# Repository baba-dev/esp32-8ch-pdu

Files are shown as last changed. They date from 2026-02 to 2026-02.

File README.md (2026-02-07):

# esp32-8ch-pdu
DIY ESPHome powered 8 Channel Power Delivery Unit with code, 3d Case &amp; Instructions.

⚡ Ultimate DIY 8-Channel ESP32 PDU - Detailed at [BabaBuilds.com - DIY PDU Guide](https://bababuilds.com/blog/diy-8-channel-esp32-pdu/)




A professional-grade, 8-channel smart Power Distribution Unit (PDU) built on the ESP32 platform. This project replaces expensive commercial smart PDUs with a fully local, highly customizable solution featuring real-time RMS monitoring, OLED telemetry, and individual relay control.

## 🚀 Features

* **8x Independent Channels:** Control up to 8 AC sockets individually via Home Assistant.
* **True RMS Monitoring:** Measures Voltage (V), Current (A), Power (W), and Energy (kWh).
* **Web UI Calibration:** Calibrate voltage and current sensors directly from the browser—no code re-uploading required.
* **OLED Dashboard:** 1.3" display showing IP address, Real-time Voltage, and Total Load.
* **Reactive Status LEDs:** WS2812b strip provides visual feedback (Rainbow=Idle, Scan=Active, Strobe=Overload).
* **Safety First:** Uses "Normally Open" relay logic and thermal circuit protection.
* **Edge Automation:** Safety limits and LED effects run locally on the ESP32, independent of Wi-Fi.

## 🛠️ Hardware Bill of Materials

* **MCU:** ESP32 DevKit V1
* **Power:** Hi-Link HLK-PM01 (5V)
* **Relays:** 8-Channel 5V Relay Module (Low-Level Trigger)
* **Voltage Sensor:** ZMPT101B AC Voltage Sensor
* **Current Sensor:** WCS1700 Hall Effect Sensor (High Amp)
* **Display:** 1.3" I2C OLED (SH1106 or SSD1306 driver)
* **LEDs:** WS2812b Addressable RGB Strip
* **Protection:** 15A Thermal Circuit Breaker
* **Wiring:** 14 AWG (2.5mm²) for Mains, 22 AWG for Logic.

## 🔌 Pinout & Wiring

| Component | Pin Function | ESP32 GPIO | Notes |
| :--- | :--- | :--- | :--- |
| **Relays 1-8** | Control | 13, 14, 27, 26, 25, 33, 32, 4 | Active HIGH in Config |
| **I2C Display** | SDA | 21 | |
| **I2C Display** | SCL | 22 | |
| **WS2812b LEDs** | Data | 18 | |
| **ZMPT101B** | Analog Out | 34 | Calibrate via Pot first |
| **WCS1700** | Analog Out | 35 | **MUST** power with 5V (VIN) |

> **⚠️ WCS1700 Note:** You must power the WCS1700 sensor from the **VIN (5V)** pin. If powered via 3.3V, sensitivity is too low to detect small loads.

## 🎛️ How to Calibrate (The "Smart" Way)

This firmware allows dynamic calibration via the Web Server.

**1. Voltage Calibration:**
* Measure your actual wall voltage with a Multimeter (e.g., 236V).
* Open the Device Web Page (IP Address).
* Enter `236` in **"Calibrate: Real Voltage"**.
* Click **Action: Calibrate Voltage**.

**2. Current Calibration:**
* Plug in a known resistive load (e.g., a 1000W Heater).
* Ensure the "PDU Current" sensor shows *some* value (not 0.00).
* Enter `1000` in **"Calibrate: Known Load (Watts)"**.
* Click **Action: Calibrate Current**.

## ⚠️ Safety Warning

**DANGER: HIGH VOLTAGE**
This project involves 110V/220V Mains Electricity. Improper wiring can cause **fire, injury, or death**.

* Always unplug mains power before opening the case.
* Use wire ferrules on all screw terminals.
* Do not rely on the relays as a safety disconnect; use the physical switch/breaker.
* **Build at your own risk.** The authors accept no liability for damage or injury.

## 📜 License

This project is licensed under the MIT License - see the [LICENSE](LICENSE) file for details.

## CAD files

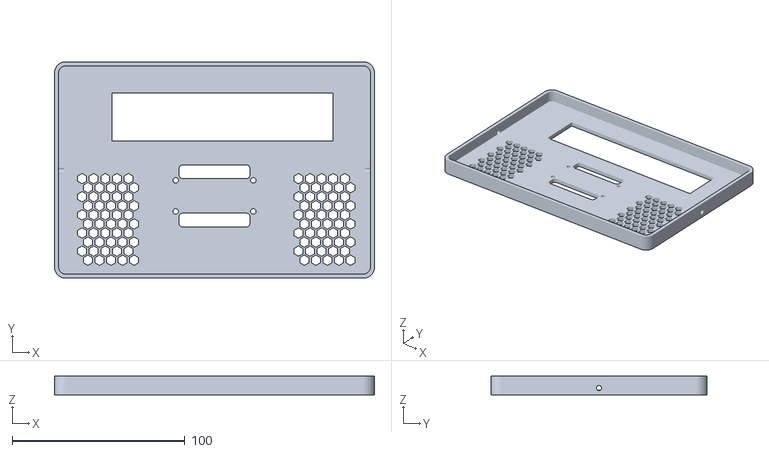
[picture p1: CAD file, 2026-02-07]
8Ch Relay Lid.stl
185.3 x 125.3 x 11.0

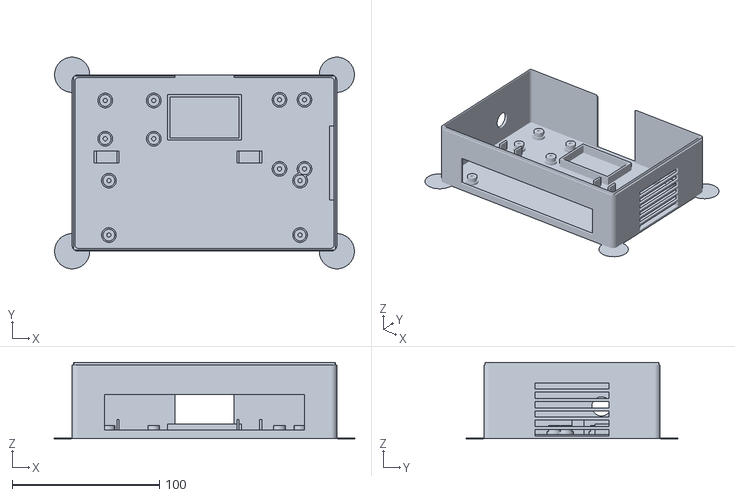
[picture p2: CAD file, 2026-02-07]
8Ch Relay box.stl
204.0 x 143.9 x 52.0

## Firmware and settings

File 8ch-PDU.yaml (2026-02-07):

esphome:
  name: esp32-8ch-pdu
  friendly_name: ESP32-8CH-PDU

esp32:
  board: esp32dev
  framework:
    type: esp-idf

# Enable logging
logger:

# Enable Home Assistant API
api:
  encryption:
    key: "KEY"

ota:
  - platform: esphome
    password: "OTAPASS"

wifi:
  ssid: !secret wifi_ssid
  password: !secret wifi_password

  # Enable fallback hotspot (captive portal) in case wifi connection fails
  ap:
    ssid: "Esp32-8Ch-Pdu Fallback Hotspot"
    password: "FALLBACK-PASS"

captive_portal:

# --- TIME SOURCE ---
time:
  - platform: sntp
    id: my_time
    timezone: "Asia/Kolkata"  # Set to your local time for correct midnight reset
    
# Enable Web Server (Optional - view status via IP address)
web_server:
  port: 80

# --- I2C & DISPLAY CONFIGURATION (NEW) ---
i2c:
  sda: 22
  scl: 21
  scan: true
  id: bus_a

font:
  - file: "gfonts://Roboto"
    id: roboto_12
    size: 12
  - file: "gfonts://Roboto"
    id: roboto_20
    size: 20

display:
  - platform: ssd1306_i2c
    model: "SSD1306 128x64"  # JMD 1.3" usually uses SH1106 driver
    address: 0x3C           # Try 0x3D if screen stays black
    id: pdu_display
    contrast: 100%
    brightness: 100%    
    i2c_id: bus_a
    lambda: |-
      // Draw Header
      it.print(0, 0, id(roboto_12), "PDU MASTER");
      
      // Draw Voltage (Large)
      it.printf(0, 16, id(roboto_20), "Load: %.0f W", id(pdu_power).state);
      
      // Draw Power & Current
      it.printf(0, 40, id(roboto_12), "%.1f V", id(pdu_voltage).state);
      it.printf(0, 52, id(roboto_12), "Amps: %.2f A", id(pdu_current).state);

# --- 1. GLOBAL VARIABLE (Stores the calibration math permanently) ---
globals:
  - id: voltage_calib_factor
    type: float
    restore_value: yes
    initial_value: '4450.0' # A safe starting guess (approx 230V / 0.051)

  - id: current_calib_factor_new 
    type: float
    restore_value: yes
    initial_value: '31.25'


# --- 2. USER INPUTS (Web UI) ---
number:
  - platform: template
    name: "Calibrate: Known Load (Watts)"
    id: calib_target_watts
    optimistic: true
    min_value: 0
    max_value: 3000
    step: 10
    mode: BOX  # Allows typing the number

# NEW: VOLTAGE CALIBRATION INPUT
  - platform: template
    name: "Calibrate: Real Voltage (Volts)"
    id: calib_target_voltage
    optimistic: true
    min_value: 0
    max_value: 300
    step: 1
    mode: BOX
    
button:
  - platform: template
    name: "Action: Calibrate Current Sensor"
    on_press:
      - lambda: |-
          // 1. Safety Checks
          if (id(pdu_voltage).state < 100) {
            ESP_LOGE("calib", "Voltage too low! Cannot calibrate.");
            return;
          }
          if (id(calib_target_watts).state < 10) {
             ESP_LOGE("calib", "Target Watts too low!");
             return;
          }

          // 2. The Math
          // Real Amps = Watts / Volts
          float real_amps = id(calib_target_watts).state / id(pdu_voltage).state;
          
          // Raw Reading from Sensor
          float raw_reading = id(pdu_current_raw).state;
          
          if (raw_reading < 0.001) {
            ESP_LOGE("calib", "Sensor reading is zero! Is the appliance on?");
            return;
          }

          // Calculate the new Ratio
          float new_factor = real_amps / raw_reading;
          
          // 3. Save & Apply
          // UPDATED: Using the NEW variable name
          id(current_calib_factor_new) = new_factor; 
          
          ESP_LOGI("calib", "Calibration Success! Real Amps: %.2f, New Factor: %.4f", real_amps, new_factor);

  - platform: template
    name: "Action: Calibrate Voltage (Volts)"
    on_press:
      - lambda: |-
          if (id(calib_target_voltage).state < 10) {
             ESP_LOGE("calib", "Target Voltage too low!");
             return;
          }
          
          // Get the raw RMS signal
          float raw_signal = id(pdu_voltage_raw).state;
          
          if (raw_signal < 0.001) {
             ESP_LOGE("calib", "Sensor signal is 0! Is it plugged in?");
             return;
          }

          // Calculate Ratio
          float new_factor = id(calib_target_voltage).state / raw_signal;
          
          // Save
          id(voltage_calib_factor) = new_factor;
          // REMOVED .save()
          
          ESP_LOGI("calib", "Voltage Calibrated! Factor: %.2f", new_factor);
# --- RELAY CONFIGURATION ---
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

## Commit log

2026-02-07 Expand README with project details and instructions
    Added detailed project description, features, hardware requirements, installation instructions, calibration guide, safety warnings, and licensing information.
2026-02-07 Add ESP32 8-channel PDU configuration
    Added configuration for ESP32 8-channel power distribution unit including WiFi, I2C, display, sensors, and relays.
